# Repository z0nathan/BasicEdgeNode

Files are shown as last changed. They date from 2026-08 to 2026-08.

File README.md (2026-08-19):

# BEN — Basic Edge Node

**A minimal desktop companion robotics platform.**

KakaoTalk_20260815_001912404

BEN is a small desktop robot built around a simple idea: how far can a desktop companion be simplified while still remaining expressive?

It keeps only the essentials:

- 2 DOF
- Single-button input
- USB-powered
- LED eyes and heart

Design files are provided as-is. Feel free to build on them, modify them, or just poke around.

## Hardware

BEN is built around an **ESP32-C3 SuperMini** and a custom flexible PCB (FPCB).

| Component | Specification |
| --- | --- |
| MCU | ESP32-C3 SuperMini |
| Degrees of freedom | 2 DOF (roll&pitch) |
| Actuators | 2 × DM-S0020 2g micro servo |
| Input | 1 × Kailh Choc V2 mechanical switch |
| LEDs | 3 × LUXEON 3535L LED |
| Power | 5 V USB C |
| PCB | Custom FPCB |
| Mechanical parts | 3D printed |

The two servos provide the neck motion, while the three LEDs provide simple visual expression.

The button on top of the head acts as BEN's primary physical input.

## Pinout

| Function | ESP32-C3 |
| --- | --- |
| Left / Right Eye LED | GPIO 0 / GPIO 3 |
| Heart LED | GPIO 1 |
| Servo 1 | GPIO 4 |
| Servo 2 | GPIO 5 |
| Head Button | GPIO 10 |
| Servo Power | 5 V |
| Logic Power | 3.3 V |
| Common Ground | GND |

The LEDs are connected through current-limiting resistors and can be brightness-controlled using PWM.

## Electronics

The complete editable electronics design is provided as a KiCad project:

```text
BEN.kicad_pro
BEN.kicad_sch
BEN.kicad_pcb
```

The files were converted and verified using **KiCad 9**.

The FPCB integrates the controller, LED connections, servo connections, and button interface into a single compact board designed to fit inside BEN.

## Mechanical Design

BEN uses a compact 2-DOF neck mechanism driven by two micro servos.

The mechanism was designed to minimize the number of actuators and mechanical components while still allowing expressive head movement.

STEP files are provided for modification and fabrication.

## Building BEN

### Electronics

Open:

```text
hardware/electronics/BEN.kicad_pro
```

The provided `.kicad_sch` and `.kicad_pcb` files contain the editable schematic and PCB design.

### Mechanical Parts



STEP file is provided under:

```text
hardware/CAD/
```

They can be modified in most CAD software or used to generate files for 3D printing.

### Firmware

The original button-triggered hardware test is provided as a standalone
ESP-IDF project in [`firmware/examples/internalTest/`](firmware/examples/internalTest/). Its local README contains
build, flash, and legacy test-pin instructions.

The [`firmware/examples/webCamMotion/`](firmware/examples/webCamMotion/)
example follows webcam head pitch and roll while laptop audio controls eye
brightness.

Feel free to modify it, add new behaviors, or use BEN as a platform for your own desktop robotics experiments.

## Building guide

A step-by-step build guide, including fabrication, assembly, wiring, and setup, is available on Instructables:
 [Instructables](https://www.instructables.com/BEN-Your-Minimal-Desktop-Companion/)

## Third-Party Resources

The project uses the following third-party resources:

* **Kailh Choc switch footprint** — [KiSwitch](https://github.com/kiswitch/kiswitch/tree/main/library/footprints/Switch_Keyboard_Kailh.pretty)
* **ESP32-C3 SuperMini symbol/footprint** — [SnapMagic / SnapEDA](https://www.snapeda.com/parts/ESP32-C3%20SuperMini_TH/Espressif%20Systems/view-part/)
* **ESP-IDF** — [Espressif IoT Development Framework](https://github.com/espressif/esp-idf), used to build the example firmware and distributed under the Apache License 2.0.
* **MediaPipe** — [Google MediaPipe](https://github.com/google-ai-edge/mediapipe), used for webcam face landmarks under the Apache License 2.0.
* **OpenCV** — [OpenCV](https://opencv.org/), used for camera capture and head-pose geometry under the Apache License 2.0.
* **NumPy** — [NumPy](https://numpy.org/), used for pose and audio calculations in the webcam bridge.
* **SoundCard** — [SoundCard](https://github.com/bastibe/SoundCard), used to capture laptop output or microphone audio.
* **pySerial** — [pySerial](https://github.com/pyserial/pyserial), used for the laptop-to-ESP32 connection.
* **pynput** — [pynput](https://github.com/moses-palmer/pynput), used to convert the physical switch event into a Space key press.

These resources remain subject to their respective original licenses and terms.

## License

BEN uses separate licenses for hardware and software.

### Hardware

CAD files, schematics, PCB designs, and other hardware design files are licensed under the **CERN Open Hardware Licence Version 2 — Weakly Reciprocal (CERN-OHL-W-2.0)**.

Commercial use and modification are allowed under the terms of the license.

See `LICENSE-HARDWARE` for details.

### Software

Firmware and software are licensed under the **MIT License**.

Commercial use and modification are allowed under the terms of the license.

See `LICENSE-SOFTWARE` for details.

---

## Community

Built something with BEN?

If you modify the hardware, develop a new behavior, or use BEN in another project, I'd love to see what you come up with.

Feel free to open an issue, submit a pull request, or share your build. Interesting modifications and projects may be featured here in the future.

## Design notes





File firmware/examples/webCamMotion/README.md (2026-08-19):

# Webcam motion bridge

KakaoTalk_20260819_121949584

This example makes the ESP32-C3 a hardware follower. The laptop bridge owns
all behavior:

- MediaPipe Face Mesh estimates a person's webcam head pitch and roll;
- pitch and roll are smoothed and mapped into the safe servo ranges;
- roll uses common-mode motion (both servos move in the same direction), while
  pitch uses differential motion (the servos move oppositely);
- laptop output audio or microphone magnitude controls both eye LEDs (5–15);
- the bridge sends heart LED brightness, eye brightness, servo targets, and
  servo attach state to the ESP32-C3;
- the ESP32-C3 reports a GPIO10 switch press as a Space key on the laptop;
- a one-second serial timeout turns LEDs off and detaches both servos.

## Build and flash the follower

```bash
cd firmware/examples/webCamMotion
source /path/to/esp-idf/export.sh
idf.py build
idf.py -p /dev/ttyACM0 flash
```

Use the board's COM port instead of `/dev/ttyACM0` on Windows. Do not run an
ESP-IDF serial monitor at the same time as the bridge.

## Install the bridge

Ubuntu:

```bash
cd firmware/examples/webCamMotion
python3 -m venv .venv
source .venv/bin/activate
python -m pip install -r requirements.txt
python webcam_bridge.py --port /dev/ttyACM0
```

Windows PowerShell:

```powershell
cd firmware/examples/webCamMotion
py -m venv .venv
.venv\Scripts\Activate.ps1
py -m pip install -r requirements.txt
py webcam_bridge.py --port COM5
```

Look naturally toward the camera during the first 30 frames. In the preview,
yellow dots mark the pose landmarks, the nose arrow shows pitch/roll direction,
the green eye line determines roll, and the magenta perpendicular from the eye
line to the nose determines pitch. Calibrated angles are shown in degrees.
Press `C` to recalibrate and `Q` or Escape to quit.

By default, laptop output audio drives the eyes. To use a microphone:

```bash
python webcam_bridge.py --port /dev/ttyACM0 --audio-source microphone
```

Useful adjustments:

```bash
python webcam_bridge.py \
  --pitch-limit-degrees 10 \
  --roll-limit-degrees 10 \
  --servo-pitch-travel 18 \
  --servo-roll-travel 18 \
  --pose-smoothing 0.18 \
  --audio-gain 12
```

Smaller pitch/roll limits produce more servo travel for the same human head
movement. Use `--invert-pitch` or `--invert-roll` if an axis follows backward.

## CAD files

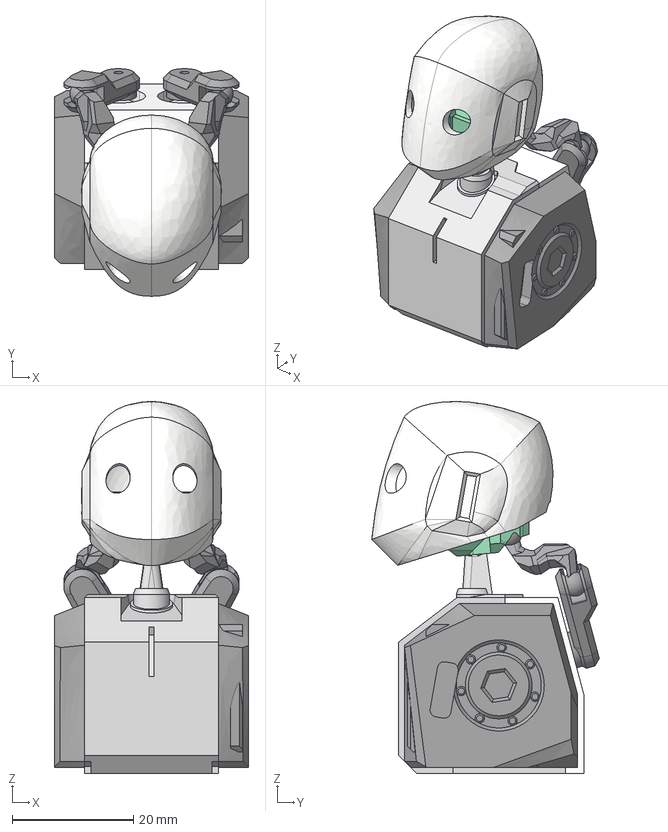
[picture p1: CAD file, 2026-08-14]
hardware/Design/BEN_assembled.step
32.0 x 37.5 x 61.3 mm
head
l1
l2
neck
torso_ft
l1(Mirror)
l2(Mirror)
torso_bk
torso_R
torso_L

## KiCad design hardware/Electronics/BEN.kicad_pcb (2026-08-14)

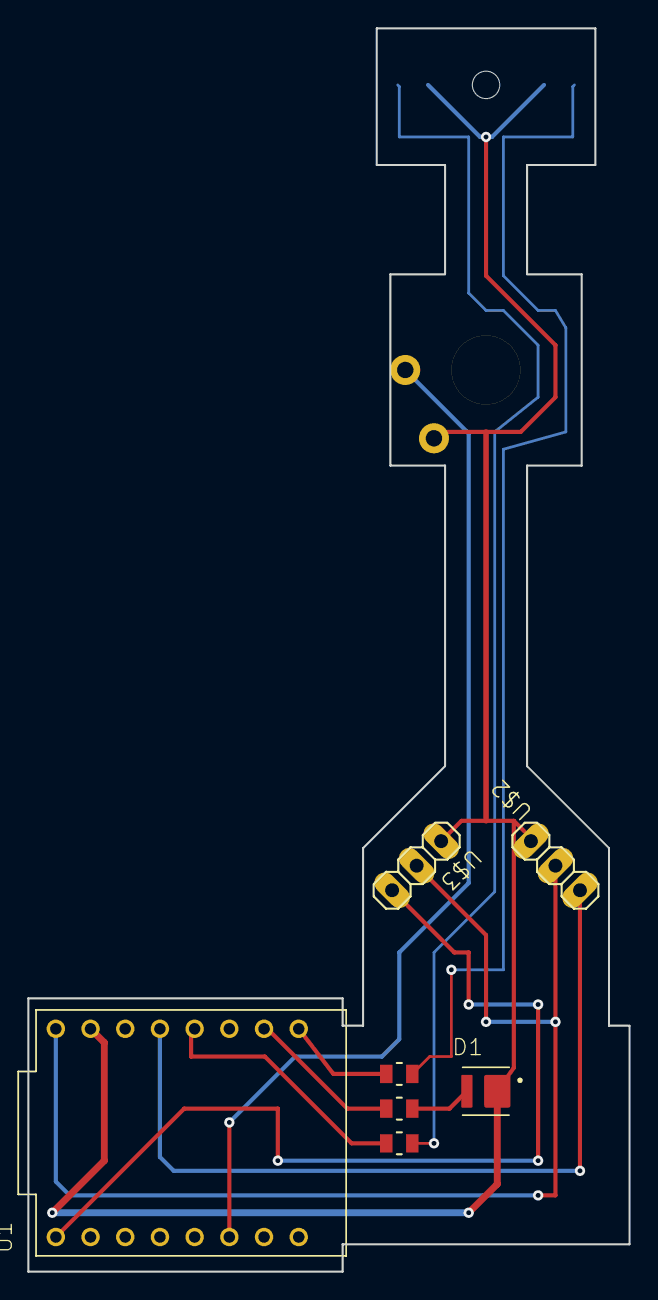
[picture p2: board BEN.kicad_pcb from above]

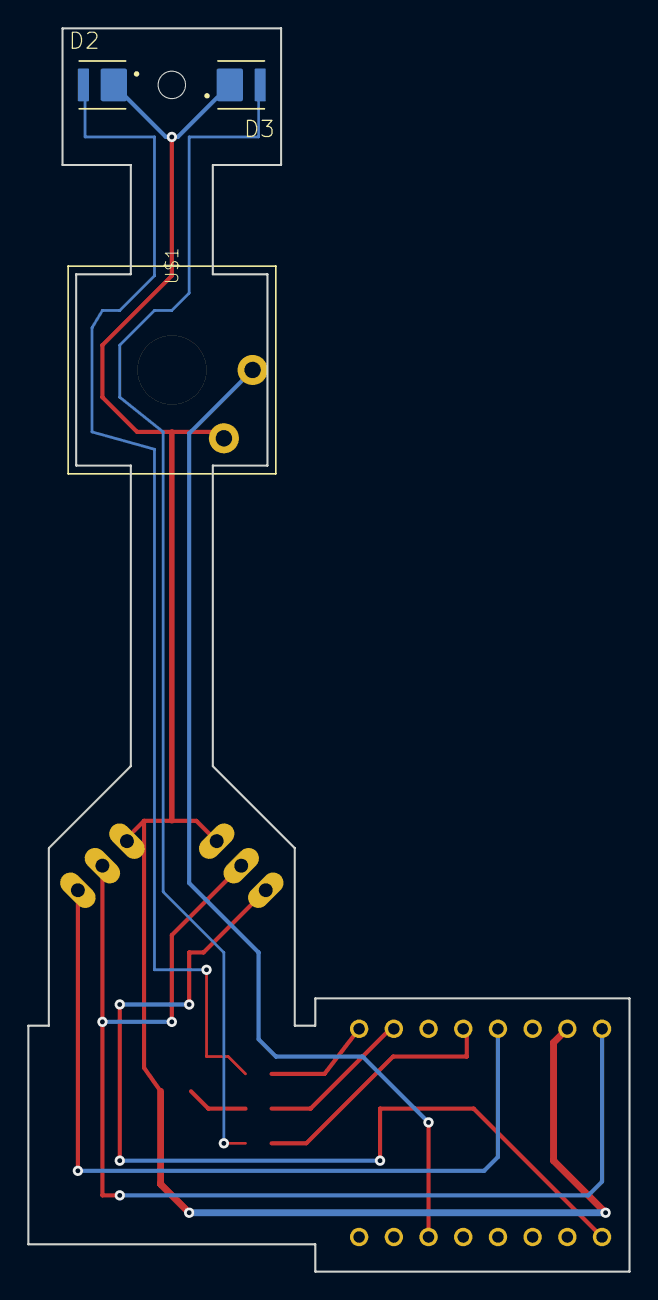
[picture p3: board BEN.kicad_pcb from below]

Board: 2 copper layers, 44.0 x 91.0 mm, 11 parts (3 on the bottom side), 11 nets.

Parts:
D1, D2, D3: L135-A589003500000; LED_L135-A589003500000_vf.D1ZenvC7SHGpa8JOMR4Mzw
R1, R2, R3: RC0805FR-07220RLRES_RC0805_YAG; RES_RC0805_YAG_vf.D1ZenvC7SHGpa8JOMR4Mzw
U1: ESP32-C3_SUPERMINI_TH; MODULE_ESP32-C3_SUPERMINI_TH_vf.D1ZenvC7SHGpa8JOMR4Mzw
U$1: CHOC_V2_CPTSW_KAILH_CHOC_V1V2_1.00U; SW_KAILH_CHOC_V1V2_1.00U_vf.D1ZenvC7SHGpa8JOMR4Mzw
U$2, U$3: SERVOSG90-HDR; 1X03_30890021
UNK_HOLE_0: dummyfp0

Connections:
unnamed: D1.A, R1.2
unnamed: D2.A, R2.2
unnamed: D3.A, R3.2
unnamed: D1.C, D2.C, D3.C, U1.G, U$1.2, U$2.1, U$3.1
unnamed: U1.5V, U$2.2, U$3.2
unnamed: U1.4, U$2.3
unnamed: U1.5, U$3.3
unnamed: U1.10, U$1.1
unnamed: R1.1, U1.1
unnamed: R2.1, U1.0
unnamed: R3.1, U1.3

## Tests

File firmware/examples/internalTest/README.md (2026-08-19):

# BEN internal hardware test

This standalone ESP-IDF project preserves the original button-triggered LED
and two-servo test sequence.

## Build

```bash
source /path/to/esp-idf/export.sh
cd firmware/examples/internalTest
idf.py build
```

To flash an attached ESP32-C3:

```bash
idf.py -p /dev/ttyACM0 flash monitor
```

Close any other serial monitor before flashing. Replace the serial port with
the correct COM port when building on Windows.

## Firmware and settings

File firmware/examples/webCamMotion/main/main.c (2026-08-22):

// BEN - Basic Edge Node
// minimal desktop robot platform for everyone.
// 
// 
// 
// Copyright (c) 2026 Minjae Kim
//
// See LICENSE for the full MIT License text.



#include <stdbool.h>
#include <stdint.h>
#include <stdio.h>

#include "driver/gpio.h"
#include "driver/ledc.h"
#include "driver/usb_serial_jtag.h"
#include "esp_err.h"
#include "esp_timer.h"
#include "freertos/FreeRTOS.h"
#include "freertos/task.h"

// The laptop owns all behavior. This firmware only follows safe targets.
#define LED1_PIN   GPIO_NUM_1
#define LED2_PIN   GPIO_NUM_0
#define LED3_PIN   GPIO_NUM_3
#define SERVO1_PIN GPIO_NUM_4
#define SERVO2_PIN GPIO_NUM_5
#define SWITCH_PIN GPIO_NUM_10

#define LED_PWM_FREQUENCY 5000

#define SERVO_PWM_FREQUENCY  50
#define SERVO_PWM_BITS       14
#define SERVO_PWM_PERIOD_US  20000
#define SERVO_MIN_US         500
#define SERVO_MAX_US         2400
#define SERVO_CENTER_ANGLE   90
#define SERVO1_MIN_ANGLE     90
#define SERVO1_MAX_ANGLE     135
#define SERVO2_MIN_ANGLE     50
#define SERVO2_MAX_ANGLE     90
#define SERVO_UPDATE_MS      15

#define SWITCH_DEBOUNCE_MS       40
#define COMMAND_TIMEOUT_MS       1000
#define PACKET_SYNC_1            0xA5
#define PACKET_SYNC_2            0x5A
#define PACKET_DATA_SIZE         6
#define COMMAND_FLAG_ATTACH      0x01

typedef enum {
    PARSER_SYNC_1,
    PARSER_SYNC_2,
    PARSER_DATA,
    PARSER_CHECKSUM,
} parser_state_t;

typedef struct {
    parser_state_t state;
    uint8_t data[PACKET_DATA_SIZE];
    uint8_t index;
} packet_parser_t;

static int servo1_angle = SERVO_CENTER_ANGLE;
static int servo2_angle = SERVO_CENTER_ANGLE;
static int servo1_target = SERVO_CENTER_ANGLE;
static int servo2_target = SERVO_CENTER_ANGLE;
static bool servos_attached = false;
static bool attach_requested = false;
static uint64_t last_command_ms = 0;

static void sleep_ms(uint32_t ms)
{
    vTaskDelay(pdMS_TO_TICKS(ms));
}

static uint64_t millis_now(void)
{
    return (uint64_t)esp_timer_get_time() / 1000;
}

static int clamp_angle(int angle, int minimum, int maximum)
{
    if (angle < minimum) {
        return minimum;
    }
    if (angle > maximum) {
        return maximum;
    }
    return angle;
}

static void set_led_brightness(ledc_channel_t channel, uint8_t brightness)
{
    ESP_ERROR_CHECK(ledc_set_duty(LEDC_LOW_SPEED_MODE, channel, brightness));
    ESP_ERROR_CHECK(ledc_update_duty(LEDC_LOW_SPEED_MODE, channel));
}

static uint32_t servo_duty_for_angle(int angle)
{
    uint32_t pulse_us = SERVO_MIN_US +
        ((uint32_t)angle * (SERVO_MAX_US - SERVO_MIN_US) / 180);
    return pulse_us * ((1U << SERVO_PWM_BITS) - 1) / SERVO_PWM_PERIOD_US;
}

static void set_servo_angle(ledc_channel_t channel, int angle)
{
    ESP_ERROR_CHECK(ledc_set_duty(
        LEDC_LOW_SPEED_MODE, channel, servo_duty_for_angle(angle)));
    ESP_ERROR_CHECK(ledc_update_duty(LEDC_LOW_SPEED_MODE, channel));
}

static void attach_servo(ledc_channel_t channel, gpio_num_t pin, int angle)
{
    ledc_channel_config_t config = {
        .gpio_num = pin,
        .speed_mode = LEDC_LOW_SPEED_MODE,
        .channel = channel,
        .intr_type = LEDC_INTR_DISABLE,
        .timer_sel = LEDC_TIMER_1,
        .duty = servo_duty_for_angle(angle),
        .hpoint = 0,
        .flags.output_invert = 0,
    };
    ESP_ERROR_CHECK(ledc_channel_config(&config));
}

static void attach_servos(void)
{
    if (servos_attached) {
        return;
    }
    attach_servo(LEDC_CHANNEL_3, SERVO1_PIN, servo1_angle);
    attach_servo(LEDC_CHANNEL_4, SERVO2_PIN, servo2_angle);
    servos_attached = true;
}

static void detach_servos(void)
{
    if (!servos_attached) {
        return;
    }
    ESP_ERROR_CHECK(ledc_stop(LEDC_LOW_SPEED_MODE, LEDC_CHANNEL_3, 0));
    ESP_ERROR_CHECK(ledc_stop(LEDC_LOW_SPEED_MODE, LEDC_CHANNEL_4, 0));
    ESP_ERROR_CHECK(gpio_reset_pin(SERVO1_PIN));
    ESP_ERROR_CHECK(gpio_reset_pin(SERVO2_PIN));
    servos_attached = false;
}

static void apply_command(const uint8_t data[PACKET_DATA_SIZE])
{
    servo1_target = clamp_angle(
        data[0], SERVO1_MIN_ANGLE, SERVO1_MAX_ANGLE);
    servo2_target = clamp_angle(
        data[1], SERVO2_MIN_ANGLE, SERVO2_MAX_ANGLE);
    set_led_brightness(LEDC_CHANNEL_0, data[2]);
    set_led_brightness(LEDC_CHANNEL_1, data[3]);
    set_led_brightness(LEDC_CHANNEL_2, data[4]);
    attach_requested = (data[5] & COMMAND_FLAG_ATTACH) != 0;
    last_command_ms = millis_now();
}

static void parse_byte(packet_parser_t *parser, uint8_t byte)
{
    if (parser->state == PARSER_SYNC_1) {
        if (byte == PACKET_SYNC_1) {
            parser->state = PARSER_SYNC_2;
        }
    } else if (parser->state == PARSER_SYNC_2) {
        if (byte == PACKET_SYNC_2) {
            parser->index = 0;
            parser->state = PARSER_DATA;
        } else {
            parser->state = byte == PACKET_SYNC_1
                ? PARSER_SYNC_2 : PARSER_SYNC_1;
        }
    } else if (parser->state == PARSER_DATA) {
        parser->data[parser->index++] = byte;
        if (parser->index == PACKET_DATA_SIZE) {
            parser->state = PARSER_CHECKSUM;
        }
    } else {
        uint8_t checksum = 0;
        for (int i = 0; i < PACKET_DATA_SIZE; ++i) {
            checksum = (uint8_t)(checksum + parser->data[i]);
        }
        if (checksum == byte) {
            apply_command(parser->data);
        }
        parser->state = PARSER_SYNC_1;
    }
}

static void update_servos(void)
{
    if (!attach_requested) {
        detach_servos();
        return;
    }

    attach_servos();
    if (servo1_angle < servo1_target) {
        ++servo1_angle;
    } else if (servo1_angle > servo1_target) {
        --servo1_angle;
    }
    if (servo2_angle < servo2_target) {
        ++servo2_angle;
    } else if (servo2_angle > servo2_target) {
        --servo2_angle;
    }
    set_servo_angle(LEDC_CHANNEL_3, servo1_angle);
    set_servo_angle(LEDC_CHANNEL_4, servo2_angle);
}

static void send_switch_event(void)
{
    static const char event[] = "EVENT:SPACE\n";
    (void)usb_serial_jtag_write_bytes(
        event, sizeof(event) - 1, pdMS_TO_TICKS(100));
}

static void configure_hardware(void)
{
    gpio_config_t switch_config = {
        .pin_bit_mask = 1ULL << SWITCH_PIN,
        .mode = GPIO_MODE_INPUT,
        .pull_up_en = GPIO_PULLUP_ENABLE,
        .pull_down_en = GPIO_PULLDOWN_DISABLE,
        .intr_type = GPIO_INTR_DISABLE,
    };
    ESP_ERROR_CHECK(gpio_config(&switch_config));

    ledc_timer_config_t led_timer = {
        .speed_mode = LEDC_LOW_SPEED_MODE,
        .duty_resolution = LEDC_TIMER_8_BIT,
        .timer_num = LEDC_TIMER_0,
        .freq_hz = LED_PWM_FREQUENCY,
        .clk_cfg = LEDC_AUTO_CLK,
        .deconfigure = false,
    };
    ESP_ERROR_CHECK(ledc_timer_config(&led_timer));

    const gpio_num_t led_pins[] = {LED1_PIN, LED2_PIN, LED3_PIN};
    for (int i = 0; i < 3; ++i) {
        ledc_channel_config_t channel = {
            .gpio_num = led_pins[i],
            .speed_mode = LEDC_LOW_SPEED_MODE,
            .channel = (ledc_channel_t)i,
            .intr_type = LEDC_INTR_DISABLE,
            .timer_sel = LEDC_TIMER_0,
            .duty = 0,
            .hpoint = 0,
            .flags.output_invert = 0,
        };
        ESP_ERROR_CHECK(ledc_channel_config(&channel));
    }

    ledc_timer_config_t servo_timer = {
        .speed_mode = LEDC_LOW_SPEED_MODE,
        .duty_resolution = LEDC_TIMER_14_BIT,
        .timer_num = LEDC_TIMER_1,
        .freq_hz = SERVO_PWM_FREQUENCY,
        .clk_cfg = LEDC_AUTO_CLK,
        .deconfigure = false,
    };
    ESP_ERROR_CHECK(ledc_timer_config(&servo_timer));
}

void app_main(void)
{
    configure_hardware();
    usb_serial_jtag_driver_config_t usb_config =
        USB_SERIAL_JTAG_DRIVER_CONFIG_DEFAULT();
    ESP_ERROR_CHECK(usb_serial_jtag_driver_install(&usb_config));

    packet_parser_t parser = {.state = PARSER_SYNC_1};
    bool previous_switch_state = true;
    bool stable_switch_state = true;
    uint64_t last_switch_change_ms = 0;
    uint64_t last_servo_update_ms = 0;
    last_command_ms = millis_now();

    while (true) {
        uint64_t now = millis_now();
        uint8_t input[32];
        int count = usb_serial_jtag_read_bytes(input, sizeof(input), 0);
        for (int i = 0; i < count; ++i) {
            parse_byte(&parser, input[i]);
        }

        if (now - last_command_ms >= COMMAND_TIMEOUT_MS) {
            attach_requested = false;
            set_led_brightness(LEDC_CHANNEL_0, 0);
            set_led_brightness(LEDC_CHANNEL_1, 0);
            set_led_brightness(LEDC_CHANNEL_2, 0);
        }

        if (now - last_servo_update_ms >= SERVO_UPDATE_MS) {
            update_servos();
            last_servo_update_ms = now;
        }

        bool current_switch_state = gpio_get_level(SWITCH_PIN) != 0;
        if (current_switch_state != previous_switch_state) {
            last_switch_change_ms = now;
        }
        if (now - last_switch_change_ms >= SWITCH_DEBOUNCE_MS &&
            current_switch_state != stable_switch_state) {
            stable_switch_state = current_switch_state;
            if (!stable_switch_state) {
                send_switch_event();
            }
        }
        previous_switch_state = current_switch_state;
        sleep_ms(5);
    }
}

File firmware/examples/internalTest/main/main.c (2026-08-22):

// BEN - Basic Edge Node
// minimal desktop robot platform for everyone.
// 
// 
// 
// Copyright (c) 2026 Minjae Kim
//
// See LICENSE for the full MIT License text.


#include <stdbool.h>
#include <stdint.h>
#include <stdio.h>

#include "driver/gpio.h"
#include "driver/ledc.h"
#include "esp_err.h"
#include "esp_timer.h"
#include "freertos/FreeRTOS.h"
#include "freertos/task.h"

// -------------------- Pin assignment --------------------
#define LED1_PIN   GPIO_NUM_1
#define LED2_PIN   GPIO_NUM_0
#define LED3_PIN   GPIO_NUM_3

#define SERVO1_PIN GPIO_NUM_4
#define SERVO2_PIN GPIO_NUM_5

#define SWITCH_PIN GPIO_NUM_10

// -------------------- LED PWM --------------------
#define LED_PWM_FREQUENCY 5000
#define LED_PWM_RESOLUTION LEDC_TIMER_8_BIT
#define LED1_MAX_BRIGHTNESS 10
#define LED2_MIN_BRIGHTNESS 2
#define LED2_MAX_BRIGHTNESS 20
#define LED3_MIN_BRIGHTNESS 2
#define LED3_MAX_BRIGHTNESS 20
#define LED_BREATH_STEP_MS  100
#define LED_BRIGHTEN_STEP_MS 8

// -------------------- Servo --------------------
#define SERVO_PWM_FREQUENCY 50
#define SERVO_PWM_BITS      14
#define SERVO_PWM_PERIOD_US 20000
#define SERVO_MIN_US        500
#define SERVO_MAX_US        2400

#define SERVO_CENTER_ANGLE 90
#define SERVO_STEP_MS      15
#define SERVO_SETTLE_MS    300
#define SEQUENCE_START_DELAY_MS 1000

#define DEBOUNCE_MS 40

static void sleep_ms(uint32_t ms)
{
    vTaskDelay(pdMS_TO_TICKS(ms));
}

static uint64_t millis_now(void)
{
    return (uint64_t)esp_timer_get_time() / 1000;
}

static ledc_channel_t led_channel_for_pin(gpio_num_t pin)
{
    if (pin == LED1_PIN) {
        return LEDC_CHANNEL_0;
    }
    if (pin == LED2_PIN) {
        return LEDC_CHANNEL_1;
    }
    return LEDC_CHANNEL_2;
}

static void set_led_brightness(gpio_num_t pin, uint8_t brightness)
{
    ledc_channel_t channel = led_channel_for_pin(pin);
    ESP_ERROR_CHECK(ledc_set_duty(LEDC_LOW_SPEED_MODE, channel, brightness));
    ESP_ERROR_CHECK(ledc_update_duty(LEDC_LOW_SPEED_MODE, channel));
}

static void led1_breath_task(void *argument)
{
    (void)argument;
    int brightness = 0;
    int direction = 1;

    while (true) {
        set_led_brightness(LED1_PIN, (uint8_t)brightness);
        brightness += direction;

        if (brightness >= LED1_MAX_BRIGHTNESS) {
            brightness = LED1_MAX_BRIGHTNESS;
            direction = -1;
        } else if (brightness <= 0) {
            brightness = 0;
            direction = 1;
        }

        sleep_ms(LED_BREATH_STEP_MS);
    }
}

typedef struct {
    int servo1_angle;
    int servo2_angle;
    uint32_t delay_after_ms;
} servo_move_t;

static int servo1_position = SERVO_CENTER_ANGLE;
static int servo2_position = SERVO_CENTER_ANGLE;

static const servo_move_t SERVO_SEQUENCE[] = {
    {.servo1_angle = 130, .servo2_angle = 50, .delay_after_ms = 250},
    {.servo1_angle = 130, .servo2_angle = 90, .delay_after_ms = 50},
    {.servo1_angle = 130, .servo2_angle = 50, .delay_after_ms = 50},
    {.servo1_angle = 90, .servo2_angle = 50, .delay_after_ms = 50},

    {.servo1_angle = 130, .servo2_angle = 50, .delay_after_ms = 350},
    {.servo1_angle = 130, .servo2_angle = 90, .delay_after_ms = 650},



    {.servo1_angle = 130, .servo2_angle = 50, .delay_after_ms = 250},
    {.servo1_angle = 90,  .servo2_angle = 90, .delay_after_ms = 250},
};

static void all_leds_off(void)
{
    set_led_brightness(LED1_PIN, 0);
    set_led_brightness(LED2_PIN, LED2_MIN_BRIGHTNESS);
    set_led_brightness(LED3_PIN, LED3_MIN_BRIGHTNESS);
}

static void brighten_action_leds(void)
{
    for (int brightness = 0;
         brightness <= (LED2_MAX_BRIGHTNESS - LED2_MIN_BRIGHTNESS) ||
         brightness <= (LED3_MAX_BRIGHTNESS - LED3_MIN_BRIGHTNESS);
         brightness += 5) {
        int led2_value = LED2_MIN_BRIGHTNESS + brightness;
        int led3_value = LED3_MIN_BRIGHTNESS + brightness;
        uint8_t led2 = led2_value < LED2_MAX_BRIGHTNESS
            ? (uint8_t)led2_value : LED2_MAX_BRIGHTNESS;
        uint8_t led3 = led3_value < LED3_MAX_BRIGHTNESS
            ? (uint8_t)led3_value : LED3_MAX_BRIGHTNESS;
        set_led_brightness(LED2_PIN, led2);
        set_led_brightness(LED3_PIN, led3);
        sleep_ms(LED_BRIGHTEN_STEP_MS);
    }

    set_led_brightness(LED2_PIN, LED2_MAX_BRIGHTNESS);
    set_led_brightness(LED3_PIN, LED3_MAX_BRIGHTNESS);
}

static uint32_t servo_duty_for_angle(int angle)
{
    uint32_t pulse_us = SERVO_MIN_US +
        ((uint32_t)angle * (SERVO_MAX_US - SERVO_MIN_US) / 180);
    return pulse_us * ((1U << SERVO_PWM_BITS) - 1) / SERVO_PWM_PERIOD_US;
}

static void set_servo_angle(ledc_channel_t channel, int angle)
{
    uint32_t duty = servo_duty_for_angle(angle);
    ESP_ERROR_CHECK(ledc_set_duty(LEDC_LOW_SPEED_MODE, channel, duty));
    ESP_ERROR_CHECK(ledc_update_duty(LEDC_LOW_SPEED_MODE, channel));
}

static void attach_servo(ledc_channel_t channel, gpio_num_t pin,
                         int current_angle)
{
    ledc_channel_config_t config = {
        .gpio_num = pin,
        .speed_mode = LEDC_LOW_SPEED_MODE,
        .channel = channel,
        .intr_type = LEDC_INTR_DISABLE,
        .timer_sel = LEDC_TIMER_1,
        .duty = servo_duty_for_angle(current_angle),
        .hpoint = 0,
        .flags.output_invert = 0,
    };
    ESP_ERROR_CHECK(ledc_channel_config(&config));
}

static void detach_servo(ledc_channel_t channel, gpio_num_t pin)
{
    ESP_ERROR_CHECK(ledc_stop(LEDC_LOW_SPEED_MODE, channel, 0));
    ESP_ERROR_CHECK(gpio_reset_pin(pin));
}

static int absolute_value(int value)
{
    return value < 0 ? -value : value;
}

// Each move has an independent target angle for each servo. Both servos remain
// attached for the entire sequence and finish each move together.
static void move_servos(servo_move_t move)
{
    int servo1_start = servo1_position;
    int servo2_start = servo2_position;
    int servo1_distance = move.servo1_angle - servo1_start;
    int servo2_distance = move.servo2_angle - servo2_start;
    int steps = absolute_value(servo1_distance);
    int servo2_steps = absolute_value(servo2_distance);

    if (servo2_steps > steps) {
        steps = servo2_steps;
    }

    for (int step = 1; step <= steps; ++step) {
        int servo1_angle = servo1_start + servo1_distance * step / steps;
        int servo2_angle = servo2_start + servo2_distance * step / steps;
        set_servo_angle(LEDC_CHANNEL_3, servo1_angle);
        set_servo_angle(LEDC_CHANNEL_4, servo2_angle);
        sleep_ms(SERVO_STEP_MS);
    }

    if (steps == 0) {
        set_servo_angle(LEDC_CHANNEL_3, move.servo1_angle);
        set_servo_angle(LEDC_CHANNEL_4, move.servo2_angle);
    }

    sleep_ms(SERVO_SETTLE_MS);
    // Do not detach here: the next sequence move keeps continuous PWM.
    servo1_position = move.servo1_angle;
    servo2_position = move.servo2_angle;
}
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

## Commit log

2026-08-14 CAD
    final version of CAD
    [Body v144.step]
2026-08-14 Rename Body v144.step to hardware/Body v144.step
    [Body v144.step]
2026-08-14 Add BEN_assembled.step file
    [BEN_assembled.step]
2026-08-14 Revise LED and power details in README
    Updated LED and power specifications in the README.
2026-10-31 Fix links in README for BEN 5mm LED version
    Updated Instagram and GitHub links for BEN 5mm LED version.
